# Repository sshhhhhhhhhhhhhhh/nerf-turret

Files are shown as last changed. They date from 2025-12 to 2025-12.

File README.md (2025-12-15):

# Nerf-Turret







Raspberry Pi based vision-guided Nerf turret developed as a course project.

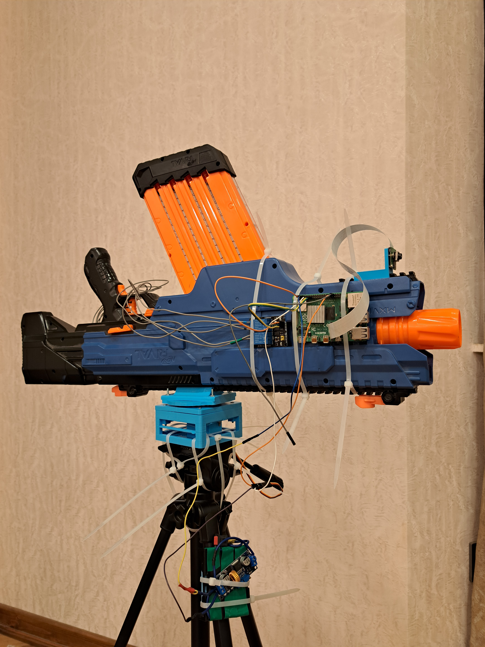
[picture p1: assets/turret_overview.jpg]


## Overview

This project implements a physical, vision-based Nerf turret prototype designed for area monitoring and non-lethal response. The system uses a camera to continuously observe its surroundings, detects the presence of a person, and autonomously controls a motorized Nerf blaster to track detected targets along a horizontal axis. 

The project was developed as part of a software engineering course and serves as a prototype demonstrating the integration of computer vision, embedded control, and mechanical actuation into a single system, with an emphasis on safety, clear operational modes, and reproducible behavior on equivalent hardware.

## Key Features

- **Real-time person detection** using computer vision algorithms
- **Autonomous horizontal tracking** with servo-controlled pan mechanism
- **Relay-based Nerf blaster actuation** for controlled, non-lethal response
- **Multiple operational modes** (monitoring, active response)
- **Optional live camera feed** for remote observation
- **Remote notifications** via Telegram integration
- **Safety-first design** with software-level constraints and user controls

## System Capabilities

The system continuously captures video frames from the mounted camera and analyzes them using a human-detection algorithm. When a person is detected with sufficient confidence, the system estimates the horizontal position of the target within the frame and rotates the turret to keep the target centered using a pan servo. 

Depending on the selected system mode, the turret can remain in a safe monitoring state or execute a controlled response by activating the Nerf blaster through relay-based actuation. The system follows a continuous control loop that transitions between detection, tracking, and response behavior based on runtime conditions. Optional features, including a live camera feed and remote notifications, are implemented so they do not interfere with the core detection and control loop.

## Hardware Requirements

This is a **physical** prototype and cannot be meaningfully executed without the required hardware. Reproducing the system requires assembling the components on a Raspberry Pi setup with appropriate mechanical mounting and power delivery.

### Core Components

- **Raspberry Pi 4** (or Pi 5B)
- **Pi Camera Module** for real-time video input
- **Metal Gear Servo Motor** (MG996R or similar) for horizontal pan control
- **Nerf blaster** (modified for electronic control)
- **2-channel relay module** (active-low) for flywheel and feeder control
- **Custom 3D printed parts** for mounting and mechanical adaptations
- **5V power supply** for Raspberry Pi (2.5A minimum)
- **6V external power supply** for servo
- **DC-DC Buck Converter** (e.g., LM2596, XL4015) - According to your powering setup

### GPIO Pin Assignments

| Component | GPIO Pin | Purpose |
|---|---|---|
| Pan Servo | GPIO 12 | Horizontal rotation control |
| Flywheel Relay | GPIO 17 | Nerf blaster motor control |
| Feeder Relay | GPIO 27 | Dart feeding mechanism |

**3D printed mounting components:** See [`assets/3d-models/`](assets/3d-models/) for STL files and assembly guide

The system is designed to operate safely with non-lethal projectiles only and includes mechanisms for user control, safe mode operation, and immediate shutdown capabilities. 

**For complete hardware setup, wiring diagrams, and assembly instructions, see [`docs/hardware.md`](docs/hardware.md)**

## Reproducing the Demo (Step-by-Step)

This project is a physical prototype and requires the appropriate hardware setup to reproduce its behavior. The instructions below describe how to reproduce the demonstrated functionality on a Raspberry Pi-based system with equivalent components.

### Prerequisites

Before starting, ensure you have:
- A fully assembled system with mounted camera, servo mechanism, and relay-controlled Nerf blaster
- The device placed on a stable surface with a clear and unobstructed field of view
- Indoor lighting conditions sufficient for person detection
- A Raspberry Pi running a Linux-based operating system (Raspberry Pi OS recommended)
- Python 3.7 or higher installed

### Installation

1. Clone the repository onto the Raspberry Pi:
   ```bash
   git clone https://github.com/sshhhhhhhhhhhhhhh/nerf-turret.git
   cd nerf-turret
   ```

2. Install the required Python dependencies:
   ```bash
   pip install -r requirements.txt
   ```

3. Enable the camera interface in the Raspberry Pi system configuration:
   ```bash
   sudo raspi-config
   # Navigate to Interface Options → Camera → Enable
   ```

4. Verify hardware connections match the GPIO pin assignments described in `docs/hardware.md`

### Running the System

1. Navigate to the source directory:
   ```bash
   cd src
   ```

2. Launch the main control script:
   ```bash
   python main.py
   ```

3. Observe system initialization messages indicating successful camera and hardware setup

4. Place a person within the camera's field of view to test detection and tracking

### Expected Behavior

When running correctly, the system initializes in a monitoring state and begins capturing video frames. Upon detecting a person, the turret rotates horizontally to track the target and center them in the frame. If active response mode is enabled, the system triggers the Nerf blaster in a controlled manner after maintaining target lock. System state changes and detection events are logged to the console during operation.

## System Architecture

The turret runs as a continuous control loop on the Raspberry Pi. Each iteration captures a camera frame, runs person detection, selects a target (if present), and updates the pan servo to reduce horizontal offset from the frame center. Based on user configuration (e.g., active response enabled/disabled) and current detection status, the system may trigger relay-based actuation for the blaster. Optional subsystems such as live preview and Telegram logging are implemented so they do not block or destabilize the main loop.

More details, including system diagrams and state machine documentation, are available in `docs/architecture.md`.

## Project Structure

```
nerf-turret/
├── assets/          # Photos, diagrams, and media files
├── docs/            # Detailed documentation
│   └── hardware.md  # Complete hardware setup guide
├── scripts/         # Utility scripts for testing and calibration
├── src/             # Main source code
│   └── main.py      # Primary turret control script
├── DEMO.md          # Demonstration guide and expected behavior
├── requirements.txt # Python dependencies
└── README.md        # This file
```

## Safety Notes

- This system uses **non-lethal foam projectiles only**
- Always operate in a controlled environment with appropriate safety measures
- The system includes software-level safety constraints to prevent unintended activation
- Emergency stop functionality is available through keyboard interrupt (Ctrl+C)
- Review `docs/safety.md` before operating the system

## Media

Visual materials, including project photos, mechanical modifications, and system diagrams, are indexed in [`assets/media.md`](assets/media.md).

## References

- Raspberry Pi Foundation. Raspberry Pi Documentation.  
  https://www.raspberrypi.com/documentation/

- OpenCV. OpenCV Documentation.  
  https://docs.opencv.org/

- Telegram Bot API Documentation.  
  https://core.telegram.org/bots/api

- TensorFlow Lite Models.  
  https://www.tensorflow.org/lite/models

- Tolga Özuygur. *Automated Nerf Turret*.  
  https://www.youtube.com/watch?v=0b1APorlbUA

> **Note:** This project was inspired by earlier automated Nerf turret work, particularly the project demonstrated by Tolga Özuygur. This implementation was developed independently as part of a course project.

## License

This project is licensed under the MIT License - see the [LICENSE](LICENSE) file for details.

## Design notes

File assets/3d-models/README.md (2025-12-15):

# 3D Printed Components

Custom-designed mounting system for the Nerf turret with ball-bearing rotation mechanism.

---

## 1. Servo Housing - Bottom
**File:** `main_part_FINAL.stl`

**Purpose:** Securely holds the servo motor with the rotation shaft precisely aligned to the geometric center of the housing. Includes cable routing gaps for servo wires.

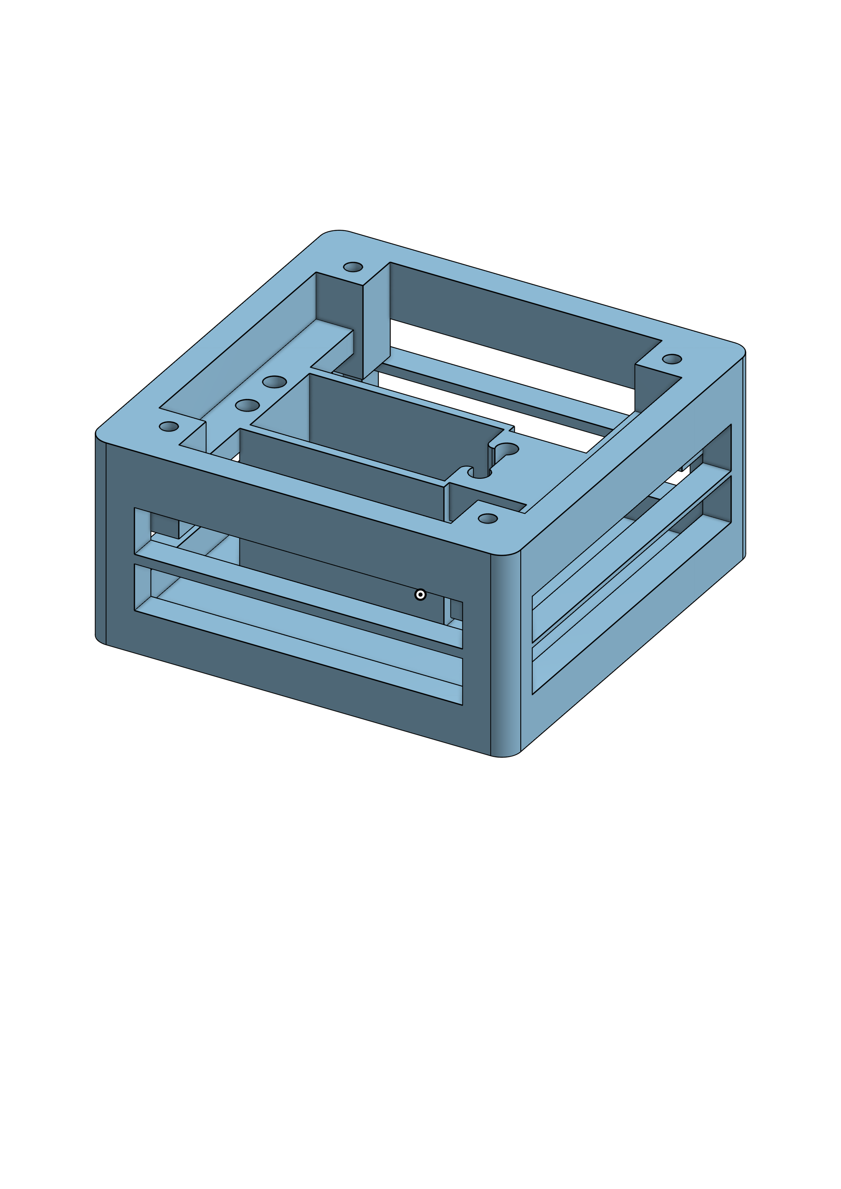
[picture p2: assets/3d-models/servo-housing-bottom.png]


---

## 2. Servo Housing - Top
**File:** `top_panel_finall.stl`

**Purpose:** Top cover with integrated circular race channel for 0.6mm airsoft BBs. Creates the lower surface of the ball bearing mechanism. Attaches to bottom housing via screw holes.

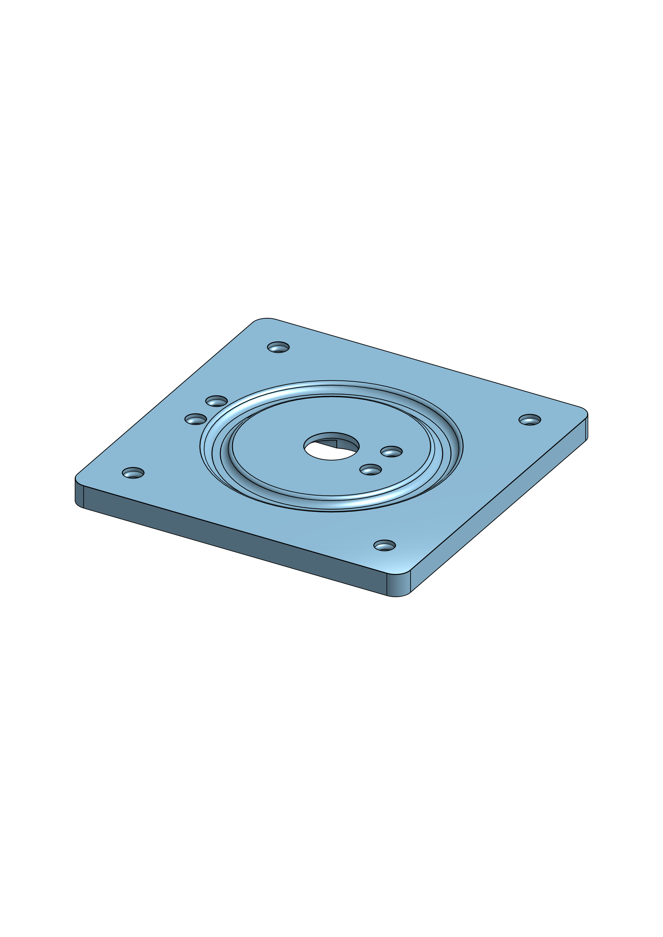
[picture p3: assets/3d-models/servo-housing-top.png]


---

## 3. Rotating Platform
**File:** `rotating-platform.stl`

**Purpose:** Sits on the airsoft BB race and rotates smoothly. Connects to the servo horn via center screw hole. Provides mounting surface for the tactical rail adapter.

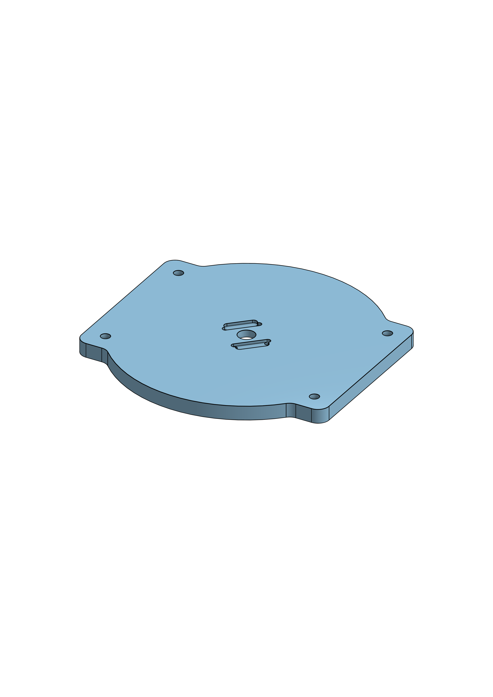
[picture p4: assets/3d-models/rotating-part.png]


---

## 4. Tactical Rail Mount
**File:** `tactical_rail_final_2.stl`

**Purpose:** Adapter that attaches to the rotating platform and provides a standard tactical rail interface for mounting the Nerf blaster.

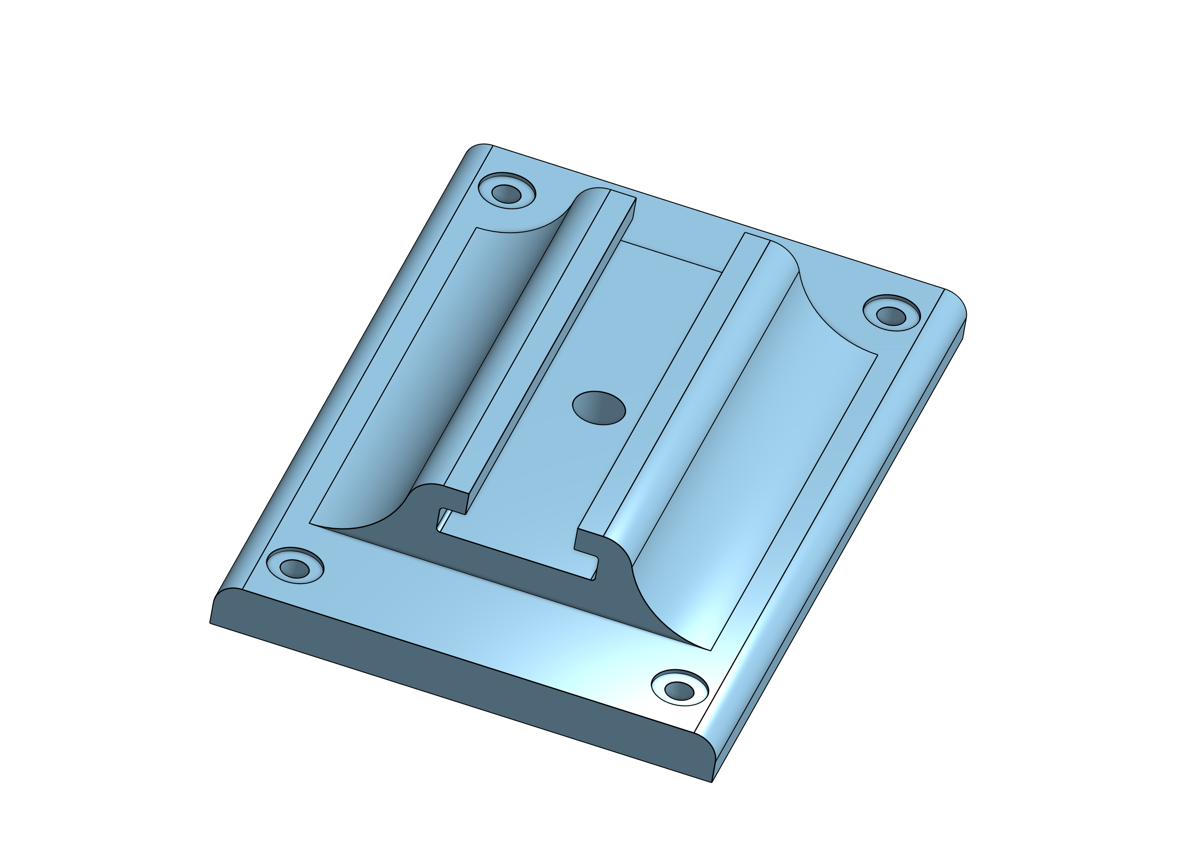
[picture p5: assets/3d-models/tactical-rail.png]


---

## Assembly Overview

1. Insert servo into bottom housing
2. Place top housing and fill race with some airsoft BBs (0.6mm) until you cannot fill further more. 
3. Mount rotating platform on BB race
4. Attach servo horn through center hole
5. Install tactical rail mount on platform
6. Slide Nerf blaster onto tactical rail

---

## Required Hardware

- **0.6mm airsoft BBs:** ~50 pieces (for ball bearing race)
- **Screws:** 8-12 pieces (various lengths for assembly)
- **Servo motor:** MG996R or similar metal gear servo

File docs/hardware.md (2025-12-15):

# Hardware Setup Guide

## Required Components

### Electronics
- **Raspberry Pi 4** (or Pi 5)
- **Pi Camera Module** (or USB webcam)
- **Metal Gear Servo Motor** (e.g., MG996R or similar)
- **2-Channel Relay Module** (active-low configuration)
- **5V Power Supply** for Raspberry Pi (3A minimum)
- **External Power Supply** for servo (6V recommended)
- **DC-DC Buck Converter** (e.g., LM2596, XL4015) - According to your powering setup
- **Jumper wires** 

### Mechanical
- **Nerf Blaster** (modified for electronic control)
- **3D Printed Mounts** (custom designed - see [`assets/3d-models/`](../assets/3d-models/))
  - Servo housing with ball bearing race
  - Rotating platform
  - Tactical rail adapter
- **Tripod or Stable Base**
- **0.6mm Airsoft BBs** (for ball bearing race)
- **Hardware** (screws for assembly)

### Optional
- Breadboard for testing
- Heat sinks for Raspberry Pi

## GPIO Pin Assignments

| Component | GPIO Pin | Physical Pin | Notes |
|---|---|---|---|
| Pan Servo | GPIO 12 | Pin 32 | PWM control |
| Flywheel Relay | GPIO 17 | Pin 11 | Keeps motors spinning |
| Feeder Relay | GPIO 27 | Pin 13 | Pushes darts |
| Camera | CSI Port | Camera ribbon cable | Use Pi Camera Module |

**Important:** All GPIO pin numbers use BCM numbering (not physical pin numbers).

## Wiring Diagram

```mermaid
graph TB
    subgraph "Power Supplies"
        PS1[5V Power Supply<br/>3A min]
        PS2[6V Power Supply<br/>Servo]
    end
    
    subgraph "Raspberry Pi"
        Pi[Raspberry Pi 4]
        GPIO12[GPIO 12<br/>Pin 32]
        GPIO17[GPIO 17<br/>Pin 11]
        GPIO27[GPIO 27<br/>Pin 13]
        Pi5V[5V Pin<br/>Pin 2/4]
        PiGND[GND Pin<br/>Pin 6/9/14/20/25/30/34/39]
    end
    
    subgraph "Servo Motor"
        Servo[Metal Gear Servo<br/>MG996R]
        ServoSig[Signal - Orange/Yellow]
        ServoPwr[Power - Red]
        ServoGnd[Ground - Brown/Black]
    end
    
    subgraph "2-Channel Relay Module"
        RelayMod[Relay Module<br/>Active-Low]
        RelayVCC[VCC]
        RelayGND[GND]
        RelayIN1[IN1 - Flywheel]
        RelayIN2[IN2 - Feeder]
        RelayOut1[Relay 1 Output<br/>NO]
        RelayOut2[Relay 2 Output<br/>NO]
    end
    
    subgraph "Nerf Blaster"
        Flywheel[Flywheel Motors]
        Feeder[Feeder Motor]
        BlasterPwr[Motor Power Supply]
    end
    
    subgraph "Camera"
        PiCam[Pi Camera Module]
        CamRibbon[CSI Ribbon Cable]
    end
    
    %% Power connections
    PS1 -->|5V| Pi
    PS2 -->|6V +| ServoPwr
    PS2 -->|GND| ServoGnd
    
    %% Servo connections
    GPIO12 -->|PWM Signal| ServoSig
    PiGND -->|Common Ground| ServoGnd
    
    %% Relay connections
    Pi5V --> RelayVCC
    PiGND --> RelayGND
    GPIO17 --> RelayIN1
    GPIO27 --> RelayIN2
    
    %% Relay to motors
    RelayOut1 --> Flywheel
    RelayOut2 --> Feeder
    BlasterPwr -->|Motor Power| Flywheel
    BlasterPwr -->|Motor Power| Feeder
    
    %% Camera connection
    Pi -->|CSI Port| CamRibbon
    CamRibbon --> PiCam
    
    %% Common ground note
    ServoGnd -.->|Share Common<br/>Ground| PiGND
    
    style Pi fill:#e1f5ff
    style Servo fill:#ffe1e1
    style RelayMod fill:#fff4e1
    style Flywheel fill:#ffe1e1
    style Feeder fill:#ffe1e1
    style PiCam fill:#e1ffe1
```

### Connection Details

**Servo Motor:**    
```
Servo Signal (Orange/Yellow) → GPIO 12 (Pin 32)
Servo Power (Red)            → External 6V supply (+)
Servo Ground (Brown/Black)   → External 6V supply (-) AND Pi GND
```

**Relay Module (Active-Low):**
```
Relay VCC  → Pi 5V (Pin 2 or 4)
Relay GND  → Pi GND (Pin 6, 9, 14, 20, 25, 30, 34, or 39)
Relay IN1  → GPIO 17 (Pin 11) - Controls Flywheel
Relay IN2  → GPIO 27 (Pin 13) - Controls Feeder
```

**Relay Outputs to Nerf Motors:**
```
Relay 1 Output (NO) → Flywheel Motors → Motor Power Supply
Relay 2 Output (NO) → Feeder Motor    → Motor Power Supply
```

**Pi Camera:**
```
Camera Ribbon Cable → Raspberry Pi CSI Camera Port
```

**Critical:** All power supplies must share a **common ground** for proper operation.

## Physical Assembly

### 1. Nerf Blaster Modification
- Open the blaster casing
- Identify flywheel motor wires
- Identify dart pusher/feeder motor wires
- Wire flywheel motors to Relay 1 output (NO - Normally Open)
- Wire feeder motor to Relay 2 output (NO - Normally Open)
- Route wires through casing cleanly

### 2. Mounting
- Attach servo to 3D printed pan mount
- Mount Nerf blaster on servo output shaft
- Secure camera pointing in same direction as blaster
- Ensure camera has unobstructed field of view
- Mount entire assembly on tripod or stable base

### 3. Cable Management
- Keep power cables separate from signal cables
- Secure loose wires with zip ties
- Ensure servo can rotate freely without cable interference
- Leave enough slack for full range of motion

## Software Setup

### 1. Enable Camera Interface
```bash
sudo raspi-config
# Navigate to: Interface Options → Camera → Enable
# Reboot when prompted
```

### 2. Install pigpio Daemon
```bash
sudo apt-get update
sudo apt-get install pigpio python3-pigpio
sudo systemctl enable pigpiod
sudo systemctl start pigpiod
```

### 3. Test Camera
```bash
libcamera-hello --timeout 5000
# Should show camera preview for 5 seconds
```

### 4. Test Servo
Create a test file:
```python
from gpiozero import Servo
from gpiozero.pins.pigpio import PiGPIOFactory
import time

factory = PiGPIOFactory()
servo = Servo(12, pin_factory=factory)

servo.min()
time.sleep(1)
servo.mid()
time.sleep(1)
servo.max()
time.sleep(1)
```

## Calibration

### Servo Range Calibration
The servo scan range is defined in the code:
- `SCAN_LEFT = -0.2` (leftmost position)
- `SCAN_RIGHT = 0.8` (rightmost position)

Adjust these values in the code if your servo hits physical limits or doesn't scan wide enough.

### Fire Zone Calibration
- `FIRE_ZONE = 12` pixels from center
- Increase for easier firing (less precision needed)
- Decrease for tighter accuracy (harder to trigger)

### Detection Threshold
- `CONFIDENCE_THRESHOLD = 0.5` (50% confidence)
- Increase to reduce false positives
- Decrease for better detection in poor lighting

## Safety Notes

⚠️ **IMPORTANT SAFETY WARNINGS:**
- Never point the turret at faces or eyes
- Test in a controlled environment
- Ensure emergency stop (Ctrl+C) is accessible
- Keep clear of servo motion range during operation
- Verify relay wiring before connecting high-current loads
- Use appropriate power supplies for all components

## Troubleshooting

### Camera Issues
- **"Camera not detected"**: Check ribbon cable connection, enable camera in raspi-config
- **Poor image quality**: Adjust focus ring on camera lens, improve lighting

### Servo Issues  
- **Servo jittering**: Check power supply, ensure pigpiod is running
- **Servo not moving**: Verify GPIO 12 connection, check servo power supply
- **Limited range**: Adjust SCAN_LEFT/SCAN_RIGHT values in code

### Relay Issues
- **Relays clicking but motors not running**: Check relay output wiring, verify motor power supply
- **No relay clicking**: Check relay module power (VCC/GND), verify GPIO 17/27 connections

### Detection Issues
- **No detections**: Improve lighting, lower CONFIDENCE_THRESHOLD
- **Too many false detections**: Increase CONFIDENCE_THRESHOLD

## Reference Photos

- `assets/wiring_overview.jpg`
- `assets/servo_mount.jpg`
- `assets/relay_connections.jpg`
- `assets/full_assembly.jpg`

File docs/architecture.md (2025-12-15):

# System Architecture

## Overview

The Nerf turret is built as a **real-time control system** with a continuous feedback loop. The system captures video frames, detects people, tracks targets by adjusting servo position, and executes responses based on configuration and detection status.

## High-Level Architecture

```mermaid
graph TB
    subgraph "MAIN CONTROL LOOP"
        Camera[Camera Capture]
        Detection[Detection Engine]
        Tracking[Tracking Logic]
        Response[Response Control]
        
        Camera -->|RGB Frame| Detection
        Detection -->|Bounding Box| Tracking
        Tracking -->|Servo Position| Response
    end
    
    subgraph "HARDWARE ABSTRACTION LAYER"
        CamAPI[Camera API]
        GPIO[GPIO Control]
        ServoCtrl[Servo Control]
    end
    
    Camera --> CamAPI
    Tracking --> ServoCtrl
    Response --> GPIO
    
    subgraph "PHYSICAL HARDWARE"
        PiCam[Pi Camera]
        Relays[Relay Module]
        Servo[Servo Motor]
    end
    
    CamAPI --> PiCam
    GPIO --> Relays
    ServoCtrl --> Servo
    
    Relays --> Blaster[Nerf Blaster]
    Servo --> Blaster
```

---

## Core Components

### 1. Camera Capture Module

```mermaid
flowchart LR
    A[Pi Camera] -->|30 FPS| B[Picamera2 API]
    B -->|RGB Array| C[Optional 180° Rotation]
    C -->|Frame| D[Detection Engine]
    C -->|Frame| E[HTTP Stream Server]
```

**Purpose:** Continuously captures video frames from the Pi Camera

**Implementation:**
- Uses `Picamera2` library for camera interface
- Captures at 640x480 resolution
- Optional 180° rotation for inverted mounting
- Runs in main thread (blocking capture)

**Key Code:**
```python
picam2 = Picamera2()
config = picam2.create_preview_configuration(main={"size": (640, 480)})
picam2.configure(config)
raw = picam2.capture_array()  # Gets frame as numpy array
```

---

### 2. Detection Engine

```mermaid
flowchart TB
    A[RGB Frame] --> B[BGR Conversion]
    B --> C[Blob Creation]
    C --> D[MobileNet-SSD<br/>Neural Network]
    D --> E[Detection Results]
    E --> F{Class 15<br/>Person?}
    F -->|No| G[Continue Scanning]
    F -->|Yes| H{Confidence<br/>>50%?}
    H -->|No| G
    H -->|Yes| I[Valid Detection]
    I --> J[Calculate Bounding Box]
    J --> K[Select Best Target]
    K --> L[Output to Tracking]
```

**Purpose:** Identifies people in captured frames using computer vision

**Implementation:**
- Uses **MobileNet-SSD** pre-trained model
- Detects 20 object classes (we filter for class 15 = person)
- Confidence threshold: 50% (adjustable)
- Runs inference on every captured frame

**Key Algorithm:**
```python
# Convert to blob for neural network
blob = cv2.dnn.blobFromImage(frame, 0.007843, (300, 300), 127.5)
net.setInput(blob)
detections = net.forward()

# Filter for people (class 15) above threshold
for detection in detections:
    if class_id == 15 and confidence > 0.5:
        # Valid person detected
        bounding_box = calculate_box(detection)
```

**Output:** 
- `None` if no person detected
- `(x1, y1, x2, y2)` bounding box coordinates if person found

---

### 3. Tracking Logic

```mermaid
flowchart TB
    A[Bounding Box] --> B[Calculate Target Center]
    B --> C[Apply Exponential Smoothing]
    C --> D[Calculate Horizontal Error]
    D --> E[Compute Adaptive Speed]
    E --> F[Calculate Servo Adjustment]
    F --> G[Clamp to Valid Range]
    G --> H[Update Servo Position]
    H --> I{Error < 12px?}
    I -->|Yes| J[FIRE ZONE]
    I -->|No| K[TRACKING]
```

**Purpose:** Calculates servo adjustments to keep detected person centered

**Key Concepts:**
- **Error Calculation:** Horizontal distance between target center and frame center
- **Smoothing:** Exponential moving average to reduce jitter
- **Adaptive Speed:** Moves faster when far from target, slower when close

**Adaptive Speed Formula:**
```python
distance = abs(error_x)
speed_factor = min(distance / 300, 1.0)  # Normalize to [0, 1]
adaptive_speed = 0.02 + (0.20 - 0.02) × speed_factor
# Result: 0.02 (near center) to 0.20 (far from center)
```

---

### 4. Response Control

```mermaid
flowchart TB
    A{Person Detected?} -->|Yes| B[Switch to TRACKING]
    A -->|No| C{Time Since<br/>Last Target?}
    
    B --> D[Turn ON Flywheel]
    D --> E{Error < Fire Zone?}
    
    E -->|Yes| F[Turn ON Feeder]
    E -->|No| G[Turn OFF Feeder]
    
    F --> H[FIRING]
    G --> I[TRACKING]
    
    C -->|< 5 seconds| J[Keep Motors ON]
    C -->|> 5 seconds| K[Turn OFF All Motors]
    K --> L[Return to SCANNING]
```

**Purpose:** Manages firing mechanism based on tracking state

**Hardware Control:**
```python
# Active-low relays (LOW = ON, HIGH = OFF)
GPIO.output(FLYWHEEL_PIN, GPIO.LOW)   # Turn ON flywheel
GPIO.output(FEEDER_PIN, GPIO.LOW)     # Turn ON feeder
```

---

## State Machine

```mermaid
stateDiagram-v2
    [*] --> SCANNING
    
    SCANNING --> TRACKING : Person Detected<br/>(Confidence > 50%)
    
    state SCANNING {
        [*] --> PanLeft
        PanLeft --> PanRight : Reached Left Limit
        PanRight --> PanLeft : Reached Right Limit
    }
    
    state TRACKING {
        [*] --> FollowTarget
        FollowTarget --> Firing : Error < 12px
        Firing --> FollowTarget : Error > 12px
    }
    
    TRACKING --> SCANNING : No Target for 5s
    
    note right of SCANNING
        • Servo sweeps L↔R
        • All motors OFF
        • Low power mode
    end note
    
    note right of TRACKING
        • Flywheel ON
        • Feeder ON when locked
        • Active response mode
    end note
```

### SCANNING Mode
**Behavior:**
- Servo sweeps left and right at constant speed
- Scan range: -0.2 to 0.8 (servo value)
- Both motors OFF (no power consumption)
- Detection runs every frame looking for people

**State Variables:**
```python
mode = "SCANNING"
scan_direction = 1  # 1 = right, -1 = left
servo_pos += scan_direction × SCAN_STEP
```

**Transition to TRACKING:** When `confidence > 0.5` for class 15 (person)

---

### TRACKING Mode
**Behavior:**
- Servo actively follows detected person
- Flywheel motor ON continuously (fast response time)
- Feeder motor ON only when aim is good (within fire zone)
- Updates servo position based on target location

**State Variables:**
```python
mode = "TRACKING"
smooth_cx = exponential_moving_average(target_center_x)
last_target_seen_time = current_time
```

**Transition to SCANNING:** When `time_since_target > 5.0 seconds`

---

## Data Flow Pipeline

```mermaid
graph TD
    A[Pi Camera Hardware] -->|30 FPS| B[Picamera2 API]
    B -->|RGB Array| C[Frame Processing]
    C -->|BGR Frame| D[MobileNet-SSD]
    C -->|RGB Frame| E[HTTP Stream]
    
    D -->|Detections| F{Person Found?}
    F -->|No| G[Continue Loop]
    F -->|Yes| H[Calculate Target Center]
    
    H --> I[Apply Smoothing]
    I --> J[Calculate Error]
    J --> K[Adaptive Speed]
    K --> L[Servo Adjustment]
    
    L --> M[gpiozero PWM]
    M --> N[Servo Motor]
    
    J --> O{In Fire Zone?}
    O -->|Yes| P[Activate Feeder]
    O -->|No| Q[Deactivate Feeder]
    
    P --> R[RPi.GPIO]
    Q --> R
    R --> S[Relay Module]
    S --> T[Nerf Blaster]
    
    style A fill:#e1f5ff
    style T fill:#ffe1e1
    style D fill:#fff4e1
```

---

## Timing and Performance

```mermaid
gantt
    title Control Loop Timing (per iteration)
    dateFormat X
    axisFormat %L ms
    
    Frame Capture           :a1, 0, 33
    BGR Conversion          :a2, 33, 5
    Detection Inference     :a3, 38, 120
    Tracking Calculation    :a4, 158, 5
    Servo Update            :a5, 163, 2
    GPIO Update             :a6, 165, 2
    
    section Total
    Complete Loop           :milestone, 167, 0
```

### Performance Metrics

| Operation | Target Time | Actual Performance | Status |
|---|---|---|---|
| Frame capture | 33ms (30 FPS) | ~33ms | ✅ |
| Detection inference | <150ms | ~100-150ms | ✅ |
| Servo response | <200ms | ~50-100ms | ✅ |
| Total loop time | <200ms | ~100-167ms | ✅ |
| Effective FPS | >5 FPS | 6-10 FPS | ✅ |
| Lost target timeout | 5000ms | Exactly 5000ms | ✅ |

---

## Module Architecture

```mermaid
classDiagram
    class MainControlLoop {
        +Camera camera
        +DetectionEngine detector
        +TrackingLogic tracker
        +ResponseControl responder
        +run()
    }
    
    class Camera {
        +Picamera2 picam2
        +capture_frame()
        +get_resolution()
    }
    
    class DetectionEngine {
        +cv2.dnn.Net model
        +detect_person(frame)
        +filter_detections()
    }
    
    class TrackingLogic {
        +float smooth_cx
        +calculate_error()
        +adaptive_speed()
        +update_servo()
    }
    
    class ResponseControl {
        +bool flywheel_on
        +bool feeder_on
        +control_motors()
        +check_fire_zone()
    }
    
    class HardwareLayer {
        +Servo servo
        +GPIO gpio
        +control_pin()
    }
    
    MainControlLoop --> Camera
    MainControlLoop --> DetectionEngine
    MainControlLoop --> TrackingLogic
    MainControlLoop --> ResponseControl
    ResponseControl --> HardwareLayer
    TrackingLogic --> HardwareLayer
```

---

## Configuration Parameters

### Vision Configuration
| Parameter | Value | Purpose |
|---|---|---|
| `CONFIDENCE_THRESHOLD` | 0.5 | Detection confidence (0-1) |
| `CAM_RES` | (640, 480) | Camera resolution |
| `FLIP_180` | 1 | Rotate image if inverted |

### Servo Configuration
| Parameter | Value | Purpose |
|---|---|---|
| `SERVO_PIN` | 12 | GPIO pin for servo |
| `SCAN_LEFT` | -0.2 | Leftmost scan position |
| `SCAN_RIGHT` | 0.8 | Rightmost scan position |
| `SCAN_STEP` | 0.015 | Movement per frame |

### Tracking Configuration
| Parameter | Value | Purpose |
|---|---|---|
| `FIRE_ZONE` | 12 | Pixels from center to fire |
| `MIN_SPEED` | 0.02 | Minimum servo speed |
| `MAX_SPEED` | 0.20 | Maximum servo speed |
| `TARGET_SMOOTHING` | 0.4 | Smoothing factor (0-1) |
| `LOST_TARGET_TIMEOUT` | 5.0 | Seconds before giving up |

### Hardware Configuration
| Parameter | Value | Purpose |
|---|---|---|
| `FLYWHEEL_PIN` | 17 | GPIO for flywheel relay |
| `FEEDER_PIN` | 27 | GPIO for feeder relay |
| `RELAY_ACTIVE_LOW` | True | Relay logic level |

---

## Threading Model

```mermaid
graph TB
    subgraph "Main Thread"
        A[Camera Capture<br/>BLOCKING]
        B[Detection Inference<br/>BLOCKING]
        C[Tracking Calculation]
        D[GPIO Updates]
        E[Frame Preparation]
        
        A --> B --> C --> D --> E --> A
    end
    
    subgraph "HTTP Server Thread"
        F[Accept Connections]
        G[Serve HTML]
        H[Stream JPEG Frames]
        
        F --> G
        F --> H
    end
    
    subgraph "Telegram Thread"
        I[Fire-and-Forget<br/>HTTP POST]
    end
    
    E -.->|Shared Frame| H
    C -.->|Event| I
    
    style A fill:#ffe1e1
    style B fill:#ffe1e1
    style F fill:#e1ffe1
    style I fill:#e1e1ff
```

---

## Error Handling Strategy

```mermaid
flowchart TB
    A[System Running] --> B{Hardware Error?}
    
    B -->|Camera Failure| C[Log Error]
    B -->|Servo Failure| C
    B -->|GPIO Failure| C
    
    C --> D[Stop Main Loop]
    D --> E[Emergency Shutdown]
    
    B -->|No Error| F{User Interrupt?}
    
    F -->|Ctrl+C| G[Graceful Shutdown]
    F -->|No| A
    
    G --> H[Turn OFF Flywheel]
    H --> I[Turn OFF Feeder]
    I --> J[Cleanup GPIO]
    J --> K[Stop Camera]
    K --> L[Close Server]
    L --> M[Send Telegram<br/>Shutdown Notice]
    M --> N[Exit]
    
    E --> H
    
    style E fill:#ff9999
    style G fill:#99ff99
```

### Graceful Shutdown Sequence

```python
try:
    while True:
        # Main loop
except KeyboardInterrupt:
    print("Stopped.")
finally:
    print("EMERGENCY STOP")
    GPIO.output(FLYWHEEL_PIN, OFF)  # 1. Motors OFF
    GPIO.output(FEEDER_PIN, OFF)
    GPIO.cleanup()                   # 2. Cleanup GPIO
    servo.value = None               # 3. Release servo
    picam2.stop()                    # 4. Stop camera
    server.shutdown()                # 5. Stop server
    telegram_log("System shutdown")  # 6. Notify
```

**Guarantees:** All motors turn OFF in <100ms

---

## Optional Features Architecture

### 1. HTTP Live Stream

```mermaid
sequenceDiagram
    participant Browser
    participant HTTPServer
    participant MainLoop
    participant Camera
    
    Browser->>HTTPServer: GET /stream
    HTTPServer->>Browser: HTTP 200 (multipart)
    
    loop Every 30ms
        Camera->>MainLoop: Capture frame
        MainLoop->>MainLoop: Process & annotate
        MainLoop->>HTTPServer: Update shared frame
        HTTPServer->>Browser: JPEG frame
    end
    
    Browser->>HTTPServer: Close connection
    HTTPServer->>HTTPServer: Stop stream
```

**Implementation:**
- Threaded HTTP server (`ThreadingMixIn`)
- MJPEG stream (multipart/x-mixed-replace)
- Frame shared via `threading.Lock()`
- JPEG quality: 70%

---

### 2. Telegram Notifications

```mermaid
sequenceDiagram
    participant System
    participant TelegramAPI
    participant User
    
    System->>System: Event occurs<br/>(e.g., Target acquired)
    System->>System: Capture frame
    System->>System: Encode JPEG
    
    System->>TelegramAPI: POST /sendPhoto<br/>(non-blocking, 5s timeout)
    
    alt Success
        TelegramAPI->>User: Push notification
        TelegramAPI->>System: 200 OK
    else Failure
        TelegramAPI->>System: Error/Timeout
        System->>System: Log error, continue
    end
    
    Note over System: Main loop never blocks
```

**Events Tracked:**
- System start/stop
- Target acquired/lost
- Firing started/stopped

---

## System Integration Diagram

```mermaid
graph TB
    subgraph "Raspberry Pi"
        subgraph "Python Application"
            Main[main.py]
            Cam[Camera Thread]
            Det[Detection Engine]
            Track[Tracking Logic]
            Resp[Response Control]
            Stream[HTTP Server]
            
            Main --> Cam
            Main --> Det
            Main --> Track
            Main --> Resp
            Main --> Stream
        end
        
        subgraph "Operating System"
            LibCam[libcamera]
            Pigpio[pigpio daemon]
            GPIO_Sys[GPIO System]
        end
        
        Cam --> LibCam
        Track --> Pigpio
        Resp --> GPIO_Sys
    end
    
    subgraph "Physical Hardware"
        PiCam[Pi Camera Module]
        Servo[MG996R Servo]
        Relay[2-Ch Relay Module]
        Blaster[Nerf Blaster]
    end
    
    LibCam <--> PiCam
    Pigpio <--> Servo
    GPIO_Sys <--> Relay
    Relay --> Blaster
    Servo --> Blaster
    
    subgraph "External Services"
        Telegram[Telegram Bot API]
        Browser[Web Browser]
    end
    
    Main -.->|HTTP POST| Telegram
    Stream -.->|MJPEG Stream| Browser
    
    style Main fill:#4a90e2
    style PiCam fill:#e1f5ff
    style Blaster fill:#ffe1e1
```

---

## Performance Optimization Strategies

```mermaid
mindmap
    root((Performance))
        Hardware
            Continuous Flywheel
                Eliminates 500ms spin-up
                Instant firing capability
            Separate Power
                Stable voltage for servo
                No brownouts
        Software
            Adaptive Speed
                Fast: far from target
                Slow: near target
                Reduces oscillation
            Target Smoothing
                EMA filter
                Reduces jitter
                Stable tracking
            Asynchronous Stream
                Non-blocking
                Independent thread
                Drops frames if slow
        Algorithm
            Single Pass Detection
                No redundant processing
            Best Target Selection
                Highest confidence
                Closest/largest
```

---

## Security & Safety Architecture

```mermaid
graph TD
    subgraph "Safety Layers"
        A[Software Timeout]
        B[GPIO Cleanup]
        C[Active-Low Relays]
        D[Emergency Stop]
        
        A -->|5s no target| E[Motors OFF]
        B -->|On exit| E
        C -->|Power loss| E
        D -->|Ctrl+C| E
    end
    
    subgraph "Security Considerations"
        F[No Authentication]
        G[Hardcoded Token]
        H[Local Network Only]
        
        F -.-> I[Low Risk<br/>Prototype]
        G -.-> I
        H -.-> I
    end
    
    style E fill:#99ff99
    style I fill:#ffff99
```

---

## Dependencies

```mermaid
graph LR
    A[main.py] --> B[picamera2]
    A --> C[opencv-python]
    A --> D[gpiozero]
    A --> E[RPi.GPIO]
    A --> F[requests]
    
    B --> G[libcamera]
    D --> H[pigpio]
    
    C --> I[MobileNetSSD<br/>Model Files]
    
    style A fill:#4a90e2
    style I fill:#ffe1e1
```

### Model Details
- **Framework:** Caffe
- **Input:** 300×300 RGB
- **Output:** 20 object classes
- **Performance:** ~100-150ms on Pi 4
- **Accuracy:** Good for 2-10m range

---

## Summary

```mermaid
mindmap
    root((Nerf Turret<br/>Architecture))
        Design Principles
            Real-time Responsiveness
                <200ms reaction
            Reliability
                Fail-safe hardware
                Graceful shutdown
            Simplicity
                Minimal threading
                Clear control flow
            Safety
                Timeouts
                Emergency stops
                Non-lethal only
        Key Features
            Vision System
                MobileNet-SSD
                6-10 FPS detection
            Tracking
                Adaptive speed
                Target smoothing
            Response
                Continuous flywheel
                Precision firing
        Educational Value
            Embedded Systems
                Sensor fusion
                State machines
                Real-time control
            Software Engineering
                Hardware abstraction
                Multi-threading
                Error handling
```

The architecture prioritizes **safe, predictable behavior** over maximum performance, making it suitable for prototype demonstration and educational purposes.

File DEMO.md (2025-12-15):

# Demo Documentation

## Demo Overview

This document describes the system demonstration and expected behavior of the Nerf turret prototype.

## What the Demo Shows

The demonstration showcases a complete autonomous surveillance and response system that:
1. Continuously monitors an area using computer vision
2. Detects when a person enters the monitored zone
3. Tracks the person by rotating horizontally
4. Executes a controlled non-lethal response (firing Nerf darts)
5. Returns to scanning mode when the person leaves

## System Behavior (Step-by-Step)

### Phase 1: System Initialization
**What happens:**
- System boots and initializes camera
- Servo motor moves to starting position
- HTTP stream server starts on port 8080
- Console displays system status and local IP address
- Telegram notification sent: "System started"

**What you see:**
```
Servo on GPIO 12
Flywheel on GPIO 17, Feeder on GPIO 27
Stream: http://192.168.1.X:8080
TURRET READY. Ctrl+C to stop
```

**Expected time:** ~3-5 seconds

---

### Phase 2: Scanning Mode
**What happens:**
- Turret slowly pans left and right in a sweeping pattern
- Camera continuously analyzes frames for people
- No motors running (flywheel OFF, feeder OFF)
- System is in "SCANNING" mode

**What you see:**
- Servo moving smoothly back and forth
- Console output: `[SCANNING] FPS: 8.50 | Fly: OFF | Feed: OFF`
- Live stream (if accessed) shows "SCANNING..." overlay
- Red vertical line at center of frame (aiming reference)

**Expected behavior:** Continuous scanning until a person is detected

---

### Phase 3: Target Acquisition
**What happens:**
- Person enters camera field of view
- Detection algorithm identifies person with >50% confidence
- Green bounding box appears around detected person
- **Mode switches from SCANNING → TRACKING**
- **Flywheel motors spin up immediately** (stays ON for entire tracking phase)
- Telegram notification sent with photo: "Target acquired"

**What you see:**
- Console output: `TARGET ACQUIRED - FLYWHEEL ON`
- Green rectangle around person on live stream
- Blue circle marking center of detected person
- Console shows: `[TRACKING] FPS: 8.50 | Fly: ON | Feed: OFF`
- Servo begins adjusting to follow person

**Expected time:** <1 second from person appearing to flywheel activation

---

### Phase 4: Tracking and Firing
**What happens:**
- Servo continuously adjusts to keep person centered
- System calculates horizontal error (distance from center)
- Movement speed adapts: faster when far from center, slower when close
- **When person is within 12 pixels of center (fire zone):**
  - Feeder motor activates
  - Darts are pushed into spinning flywheels
  - Continuous firing as long as aim is maintained
- **When person moves outside fire zone:**
  - Feeder stops (but flywheel keeps spinning)
  - System continues tracking

**What you see:**
- Person followed smoothly by camera
- When locked on target:
  - Console shows: `[TRACKING] FPS: 8.50 | Fly: ON | Feed: ON`
  - Live stream overlay: `FIRING!`
  - Telegram notification: "Firing started" (with photo)
  - Nerf darts being fired
- When tracking but not firing:
  - Console shows: `[TRACKING] FPS: 8.50 | Fly: ON | Feed: OFF`
  - Live stream overlay: `TRACKING... error: 45px` (shows distance from center)

**Expected behavior:** Darts fire in bursts as person is tracked and reacquired

---

### Phase 5: Target Loss and Timeout
**What happens:**
- Person leaves camera view or hides
- System continues tracking mode with flywheel ON
- **After 5 seconds with no detection:**
  - Flywheel motors turn OFF
  - Feeder turns OFF (if it was ON)
  - System returns to SCANNING mode
  - Telegram notification: "Target lost"

**What you see:**
- Immediately after loss:
  - Live stream overlay: `TARGET LOST (0.5s)`
  - Counter increments: `TARGET LOST (2.3s)`, `TARGET LOST (4.8s)`
  - Console shows: `[TRACKING] FPS: 8.50 | Fly: ON | Feed: OFF`
- After 5-second timeout:
  - Console: `TARGET LOST - MOTORS OFF - RESUMING SCAN`
  - Console shows: `[SCANNING] FPS: 8.50 | Fly: OFF | Feed: OFF`
  - Servo resumes scanning pattern

**Expected time:** 5 seconds from last detection to return to scanning

---

### Phase 6: System Shutdown
**What happens:**
- User presses Ctrl+C
- Emergency stop engages
- All relays turn OFF immediately
- Servo disengages
- Camera stops
- HTTP server shuts down
- Telegram notification: "System shutdown"

**What you see:**
```
^C
Stopped.
EMERGENCY STOP - ALL RELAYS OFF
```

**Expected time:** Immediate (<100ms)

---

## Live Stream Features

Access the live camera feed at `http://<raspberry-pi-ip>:8080`

**What you see on the stream:**
- Real-time camera view (640x480 resolution)
- Green bounding boxes around detected people
- Blue circle marking center of tracked target
- Red vertical crosshair at frame center
- Red circle showing fire zone radius (12 pixels)
- Status text overlay showing current mode
- Detection confidence and tracking error

**Update rate:** ~30 FPS stream, ~8 FPS detection

---

## Telegram Notifications

If enabled, the system sends notifications to configured Telegram chat:

**Notification Types:**
1. **System started** - When turret initializes
2. **Target acquired** - When person first detected (includes photo)
3. **Firing started** - When feeder activates (includes photo)
4. **Firing stopped** - When feeder deactivates
5. **Target lost** - When returning to scan after timeout
6. **System shutdown** - When Ctrl+C pressed

**Format:**
```
[2024-12-15 06:45:23]
Event: Target acquired
Mode: TRACKING
```

---

## Expected Performance Metrics

| Metric | Value |
|---|---|
| Detection FPS | 3-10 FPS |
| Detection Latency | <1 second |
| Tracking Response Time | <200ms |
| Fire Zone Accuracy | ±12 pixels from center |
| Scan Speed | Full sweep in ~15 seconds |
| Target Loss Timeout | 5 seconds |

---

## Demo Scenarios

### Scenario 1: Single Person Detection
1. System starts in SCANNING mode
2. Person walks into view from left
3. Turret locks on and tracks smoothly
4. Fires when centered
5. Person exits right
6. After 5 seconds, turret resumes scanning

**Duration:** ~30-60 seconds

---

### Scenario 2: Multiple People (Priority Selection)
1. System scanning
2. Two people enter view
3. System selects target with highest confidence
4. Tracks and fires at primary target
5. If primary target leaves, may switch to secondary target

**Note:** System tracks one target at a time (highest confidence detection)

---

### Scenario 3: Quick Movement
1. System tracking person
2. Person moves quickly across frame
3. Turret follows with adaptive speed (faster when error is large)
4. Firing occurs intermittently when aim is good
5. Demonstrates tracking capability

**Duration:** ~15-30 seconds

---

## Known Limitations

- **Single axis tracking:** Only horizontal (pan), no vertical (tilt)
- **Detection range:** ~2-10 meters depending on lighting
- **One target at a time:** Cannot track multiple people simultaneously
- **Lighting dependent:** Poor performance in very dark or very bright conditions
- **Frame rate:** 3-10 FPS (limited by Raspberry Pi processing power)
- **Accuracy:** ±12 pixels (approximately 10-15cm at 3 meters)

---

## Safety During Demo

⚠️ **Demonstration Safety Rules:**
- Clear area of fragile objects
- Participants wear safety glasses
- Maintain 2+ meter minimum distance
- Emergency stop (Ctrl+C) operator present
- Never point at faces/eyes
- Controlled indoor environment only

---

## Troubleshooting During Demo

| Issue | Quick Fix |
|---|---|
| No detection | Improve lighting, person too far |
| Jittery tracking | Normal with fast movement |
| Not firing | Person not centered in fire zone |
| Stream not loading | Check IP address, refresh browser |
| Servo not moving | Check power supply, restart pigpiod |

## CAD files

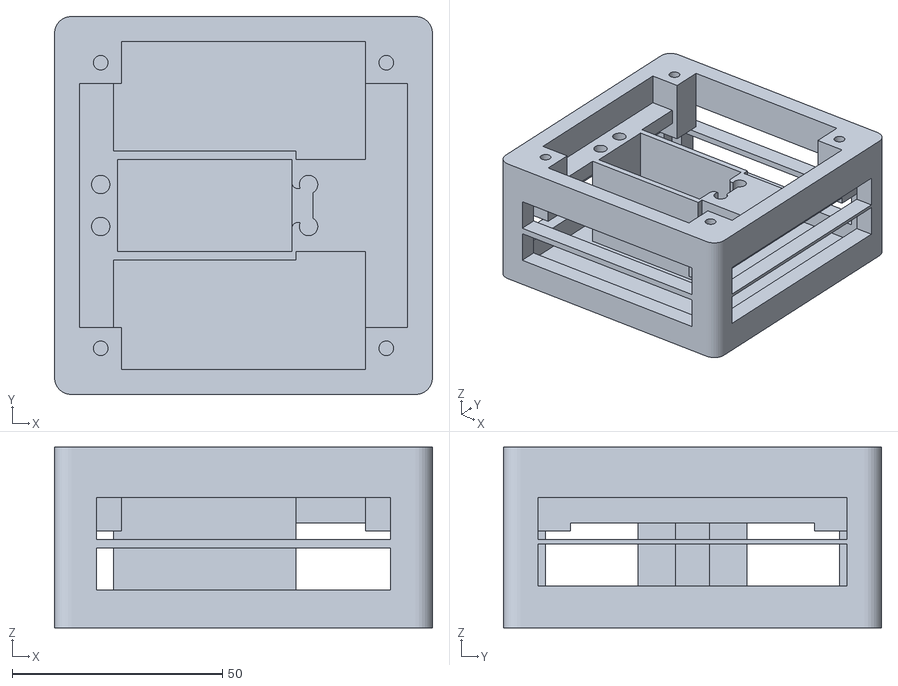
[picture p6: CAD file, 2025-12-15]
assets/3d-models/main_part_FINAL.stl
90.0 x 90.0 x 43.0

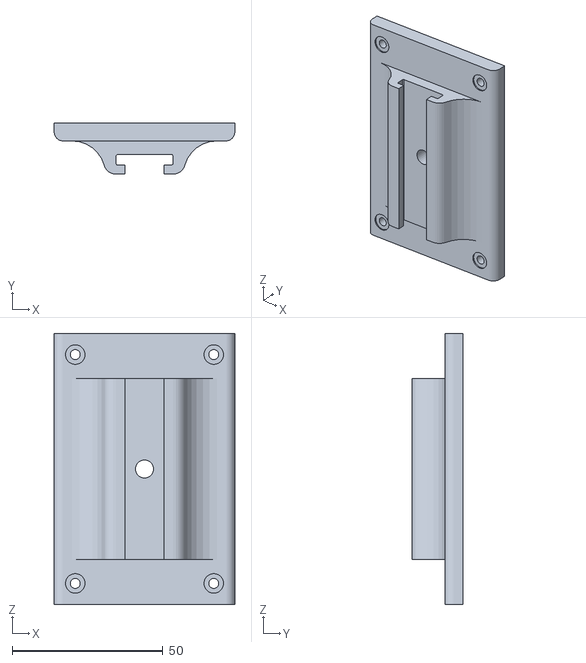
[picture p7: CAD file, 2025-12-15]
assets/3d-models/tactical_rail_final_2.stl
60.0 x 17.0 x 90.0

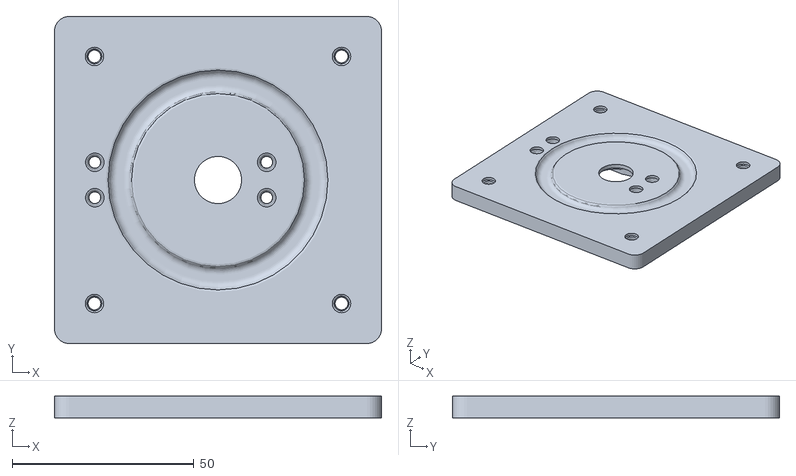
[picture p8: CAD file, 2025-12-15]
assets/3d-models/bot_final_v5.stl
90.0 x 90.0 x 6.00

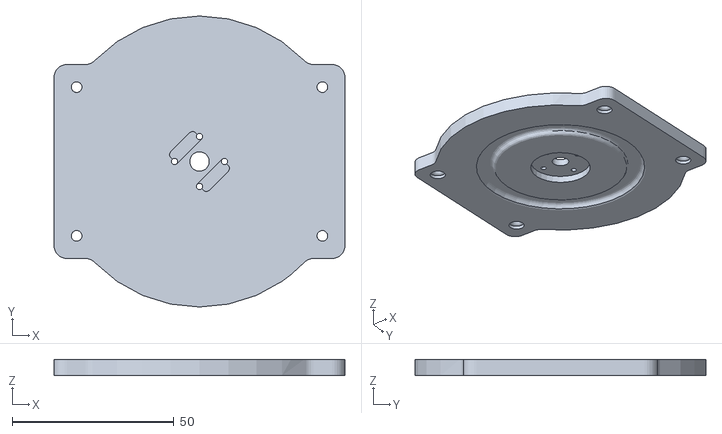
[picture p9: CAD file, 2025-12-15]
assets/3d-models/top_panel_finall.stl
90.0 x 90.0 x 5.00

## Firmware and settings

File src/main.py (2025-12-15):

import requests
from datetime import datetime
import time
import cv2
import sys, site
from http.server import HTTPServer, BaseHTTPRequestHandler
from socketserver import ThreadingMixIn
import threading
import RPi.GPIO as GPIO

site.addsitedir("/usr/lib/python3/dist-packages")
from picamera2 import Picamera2
from gpiozero import Servo
from gpiozero.pins.pigpio import PiGPIOFactory

# --------- config ----------
FLIP_180 = 1
CAM_RES = (640, 480)
CONFIDENCE_THRESHOLD = 0.5
STREAM_PORT = 8080

# Servo config
SERVO_PIN = 12

# Shooting config
FLYWHEEL_PIN = 17   # GPIO 17 - STAYS ON during entire tracking mode
FEEDER_PIN = 27     # GPIO 27 - ON only when locked on target
RELAY_ACTIVE_LOW = True

# Scanning config
SCAN_LEFT = -0.2
SCAN_RIGHT = 0.8
SCAN_STEP = 0.015

# Tracking config
FIRE_ZONE = 12  # Pixels - how close to center before we start feeding

# Smart speed adjustment
MIN_SPEED = 0.02
MAX_SPEED = 0.20
SPEED_SCALE = 300

# Smoothing
TARGET_SMOOTHING = 0.4

# Timeouts
LOST_TARGET_TIMEOUT = 5.0  # After 3 seconds of no target, turn off motors and scan

# --------- Telegram config ----------
TELEGRAM_ENABLED = True
TELEGRAM_BOT_TOKEN = "bot_token" # bot's token
TELEGRAM_CHAT_ID = chat_id # chat id of either your account or the group
# ---------------------------


current_frame = None
frame_lock = threading.Lock()

class StreamHandler(BaseHTTPRequestHandler):
    def do_GET(self):
        if self.path == '/':
            self.send_response(200)
            self.send_header('Content-type', 'text/html')
            self.end_headers()
            self.wfile.write(b'<html><body><img src="/stream" style="width:100%;max-width:800px;"></body></html>')
        elif self.path == '/stream':
            self.send_response(200)
            self.send_header('Content-type', 'multipart/x-mixed-replace; boundary=frame')
            self.end_headers()
            while True:
                with frame_lock:
                    if current_frame is None:
                        continue
                    _, jpeg = cv2.imencode('.jpg', current_frame, [cv2.IMWRITE_JPEG_QUALITY, 70])
                try:
                    self.wfile.write(b'--frame\r\n')
                    self.wfile.write(b'Content-Type: image/jpeg\r\n\r\n')
                    self.wfile.write(jpeg.tobytes())
                    self.wfile.write(b'\r\n')
                except:
                    break
                time.sleep(0.03)

    def log_message(self, format, *args):
        pass

class ThreadedHTTPServer(ThreadingMixIn, HTTPServer):
    daemon_threads = True

def gpio_levels(active_low):
    return (GPIO.LOW, GPIO.HIGH) if active_low else (GPIO.HIGH, GPIO.LOW)

def telegram_log(event, mode, image=None):
    if not TELEGRAM_ENABLED:
        return

    try:
        timestamp = datetime.now().strftime("%Y-%m-%d %H:%M:%S")
        caption = (
            f"[{timestamp}]\n"
            f"Event: {event}\n"
            f"Mode: {mode}"
        )

        if image is None:
            requests.post(
                f"https://api.telegram.org/bot{TELEGRAM_BOT_TOKEN}/sendMessage",
                data={
                    "chat_id": TELEGRAM_CHAT_ID,
                    "text": caption
                },
                timeout=5
            )
        else:
            _, jpeg = cv2.imencode(".jpg", image)
            requests.post(
                f"https://api.telegram.org/bot{TELEGRAM_BOT_TOKEN}/sendPhoto",
                data={
                    "chat_id": TELEGRAM_CHAT_ID,
                    "caption": caption
                },
                files={"photo": jpeg.tobytes()},
                timeout=10
            )
    except:
        pass


def main():
    global current_frame

    # Setup GPIO for shooting
    GPIO.setmode(GPIO.BCM)
    GPIO.setwarnings(False)
    on_level, off_level = gpio_levels(RELAY_ACTIVE_LOW)
    GPIO.setup(FLYWHEEL_PIN, GPIO.OUT, initial=off_level)
    GPIO.setup(FEEDER_PIN, GPIO.OUT, initial=off_level)

    # Setup servo
    factory = PiGPIOFactory()
    servo = Servo(SERVO_PIN, min_pulse_width=0.5/1000, max_pulse_width=2.5/1000, pin_factory=factory)
    
    servo_pos = SCAN_LEFT
    servo.value = servo_pos
    scan_direction = 1
    
    # Setup mode
    mode = "SCANNING"  # SCANNING or TRACKING
    
    smooth_cx = None
    last_target_seen_time = time.time()
    
    print(f"Servo on GPIO {SERVO_PIN}")
    print(f"Flywheel on GPIO {FLYWHEEL_PIN}, Feeder on GPIO {FEEDER_PIN}")

    # Set model & Cam
    net = cv2.dnn.readNetFromCaffe(
        "MobileNetSSD_deploy.prototxt",
        "MobileNetSSD_deploy.caffemodel"
    )

    picam2 = Picamera2()
    config = picam2.create_preview_configuration(
        main={"size": CAM_RES, "format": "RGB888"}
    )
    picam2.configure(config)
    picam2.start()
    time.sleep(0.5)

    # Set HTTPServer
    server = ThreadedHTTPServer(('0.0.0.0', STREAM_PORT), StreamHandler)
    server_thread = threading.Thread(target=server.serve_forever)
    server_thread.daemon = True
    server_thread.start()

    import socket
    s = socket.socket(socket.AF_INET, socket.SOCK_DGRAM)
    try:
        s.connect(('8.8.8.8', 80))
        ip = s.getsockname()[0]
    except:
        ip = '127.0.0.1'
    finally:
        s.close()

    print(f"Stream: http://{ip}:{STREAM_PORT}")
    print("TURRET READY. Ctrl+C to stop")

    frame_count = 0
    fps_time = time.time()
    frame_center_x = CAM_RES[0] // 2

    # Set telegram
    prev_mode = None
    prev_feeder_state = None

    telegram_log("System started", mode)

    try:
        while True:
            raw = picam2.capture_array()

            if FLIP_180:
                raw = cv2.rotate(raw, cv2.ROTATE_180)

            frame = raw.copy()
            h, w = frame.shape[:2]
            frame_bgr = cv2.cvtColor(raw, cv2.COLOR_RGB2BGR)

            blob = cv2.dnn.blobFromImage(frame_bgr, 0.007843, (300, 300), 127.5)
            net.setInput(blob)
            detections = net.forward()

            best_detection = None
            best_conf = 0

            for i in range(detections.shape[2]):
                confidence = detections[0, 0, i, 2]
                class_id = int(detections[0, 0, i, 1])

                if class_id == 15 and confidence > CONFIDENCE_THRESHOLD:
                    box = detections[0, 0, i, 3:7] * [w, h, w, h]
                    x1, y1, x2, y2 = box.astype(int)

                    cv2.rectangle(frame, (x1, y1), (x2, y2), (0, 255, 0), 2)

                    if confidence > best_conf:
                        best_conf = confidence
                        best_detection = (x1, y1, x2, y2)

            # Draw crosshair
            cv2.line(frame, (frame_center_x, 0), (frame_center_x, h), (0, 0, 255), 2)
            cv2.circle(frame, (frame_center_x, h//2), FIRE_ZONE, (0, 0, 255), 2)

            current_time = time.time()

            # === TARGET DETECTION ===
            if best_detection is not None:
                # WE SEE A TARGET!
                last_target_seen_time = current_time
                
                # Switch to TRACKING mode if we were scanning
                if mode == "SCANNING":
                    mode = "TRACKING"
                    print("TARGET ACQUIRED - FLYWHEEL ON")
                    GPIO.output(FLYWHEEL_PIN, on_level)  # TURN ON FLYWHEEL
                    
                    x1, y1, x2, y2 = best_detection
                    person_img = frame[y1:y2, x1:x2]
                    telegram_log("Target acquired", mode, person_img)

                x1, y1, x2, y2 = best_detection
                cx = (x1 + x2) // 2
                cy = (y1 + y2) // 2

                #person_img = frame[y1:y2, x1:x2]
                #telegram_log("Target acquired", mode, person_img)

                # Smooth the target position
                if smooth_cx is None:
                    smooth_cx = cx
                else:
                    smooth_cx = smooth_cx + TARGET_SMOOTHING * (cx - smooth_cx)

                error_x = smooth_cx - frame_center_x

                # Draw target center
                cv2.circle(frame, (int(smooth_cx), cy), 8, (255, 0, 0), -1)

                # === INTELLIGENT SPEED CONTROL ===
                distance = abs(error_x)
                speed_factor = min(distance / SPEED_SCALE, 1.0)
                adaptive_speed = MIN_SPEED + (MAX_SPEED - MIN_SPEED) * speed_factor
                
                # Move servo towards target
                adjustment = (error_x / frame_center_x) * adaptive_speed
                servo_pos -= adjustment
                servo_pos = max(-1.0, min(1.0, servo_pos))
                servo.value = servo_pos
                
                # === CONTINUOUS FIRING LOGIC ===
                if abs(error_x) <= FIRE_ZONE:
                    # AIM IS ON TARGET - FEED DARTS!
                    GPIO.output(FEEDER_PIN, on_level)
                    cv2.putText(frame, " FIRING! ", (10, 60), 
                               cv2.FONT_HERSHEY_SIMPLEX, 1.2, (0, 0, 255), 3)
                else:
                    # AIM IS OFF TARGET - STOP FEEDING (but flywheel stays on)
                    GPIO.output(FEEDER_PIN, off_level)
                    cv2.putText(frame, f"TRACKING... error: {int(error_x)}px", (10, 60), 
                               cv2.FONT_HERSHEY_SIMPLEX, 0.7, (0, 255, 255), 2)
                
                current_feeder_state = GPIO.input(FEEDER_PIN)
                if current_feeder_state != prev_feeder_state:
                    if current_feeder_state == on_level:
                        telegram_log("Firing started", mode, person_img)
                    else:
                        telegram_log("Firing stopped", mode)
                    prev_feeder_state = current_feeder_state

            else:
                # NO TARGET DETECTED
                smooth_cx = None
                time_since_target = current_time - last_target_seen_time
                
                # If we're in tracking mode but lost target
                if mode == "TRACKING":
                    if time_since_target > LOST_TARGET_TIMEOUT:
                        # TIMEOUT! Turn everything OFF and go back to scanning
                        print("❌ TARGET LOST - MOTORS OFF - RESUMING SCAN")
                        GPIO.output(FLYWHEEL_PIN, off_level)  # TURN OFF FLYWHEEL
                        GPIO.output(FEEDER_PIN, off_level)    # TURN OFF FEEDER
                        mode = "SCANNING"
                        telegram_log("Target lost", mode)
                    else:
                        # Just lost target, keep flywheel on, stop feeding
                        GPIO.output(FEEDER_PIN, off_level)
                        cv2.putText(frame, f"TARGET LOST ({time_since_target:.1f}s)", (10, 60), 
                                   cv2.FONT_HERSHEY_SIMPLEX, 0.7, (255, 165, 0), 2)
                
                # SCANNING MODE
                if mode == "SCANNING":
                    servo_pos += scan_direction * SCAN_STEP
                    
                    if servo_pos >= SCAN_RIGHT:
                        servo_pos = SCAN_RIGHT
                        scan_direction = -1
                    elif servo_pos <= SCAN_LEFT:
                        servo_pos = SCAN_LEFT
                        scan_direction = 1
                    
                    servo.value = servo_pos
                    cv2.putText(frame, "SCANNING...", (10, 60), 
                               cv2.FONT_HERSHEY_SIMPLEX, 0.7, (255, 255, 0), 2)

            with frame_lock:
                current_frame = frame.copy()

            frame_count += 1
            if current_time - fps_time >= 2.0:
                fps = frame_count / (current_time - fps_time)
                flywheel_state = "ON" if GPIO.input(FLYWHEEL_PIN) == on_level else "OFF"
                feeder_state = "ON" if GPIO.input(FEEDER_PIN) == on_level else "OFF"
                print(f"[{mode}] FPS: {fps:.2f} | Fly: {flywheel_state} | Feed: {feeder_state}")
                fps_time = current_time
                frame_count = 0

    except KeyboardInterrupt:
        print("\nStopped.")
    finally:
        print(" EMERGENCY STOP - ALL RELAYS OFF")
        GPIO.output(FLYWHEEL_PIN, off_level)
        GPIO.output(FEEDER_PIN, off_level)
        GPIO.cleanup()
        servo.value = None
        picam2.stop()
        server.shutdown()
        telegram_log("System shutdown", mode)

if __name__ == "__main__":
    main()

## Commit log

2025-12-15 some slight changes - added buck converters just in case
2025-12-15 3d models
    [bot_final_v5.stl, main_part_FINAL.stl, tactical_rail_final_2.stl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]
2025-12-15 some changes in hardware to make the wiring diagram look better

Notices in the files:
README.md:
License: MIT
